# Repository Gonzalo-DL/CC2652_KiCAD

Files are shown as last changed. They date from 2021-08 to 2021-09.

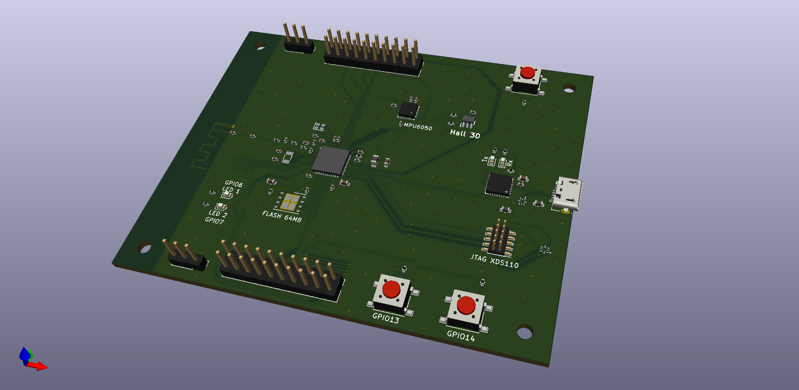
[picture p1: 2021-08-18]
CC2652_OnBoard.png

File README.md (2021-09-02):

# CC2652_KiCAD

PCB con TI CC2652R1 con BLE 5.2 y JTAG con XDS110.

Comunicacion serial via USB conectado a UART y con perifericos:

Led verde: GPIO7

Led rojo: GPIO6

Push button 1: GPIO13

Push button 2: GPIO14

Memoria Flash(W25Q64JWZPIM): (SPI) 

	SCLK: GPIO10
  
	MISO: GPIO8
  
	MOSI: GPIO9
  
	SS: GPIO20

IMU (MPU-6050): (I2C)

	SDA: GPIO24
  
	SCL: GPIO25
  
	FSYNC: GPIO26
  
	Address: 1101000

HALL 3-Axis (TLE493D): (I2C)

	SDA: GPIO24
  
	SCL: GPIO25
  
	Address: (Segun sigla del modelo)
  
		A0: 6AH / 6BH
    
		A1: 44H / 45H
    
		A2: F0H / F1H
    
		A3: 88H / 89H

USB Transceiver (CP2102N): (UART)

	Rx: GPIO19
  
	Tx: GPIO18

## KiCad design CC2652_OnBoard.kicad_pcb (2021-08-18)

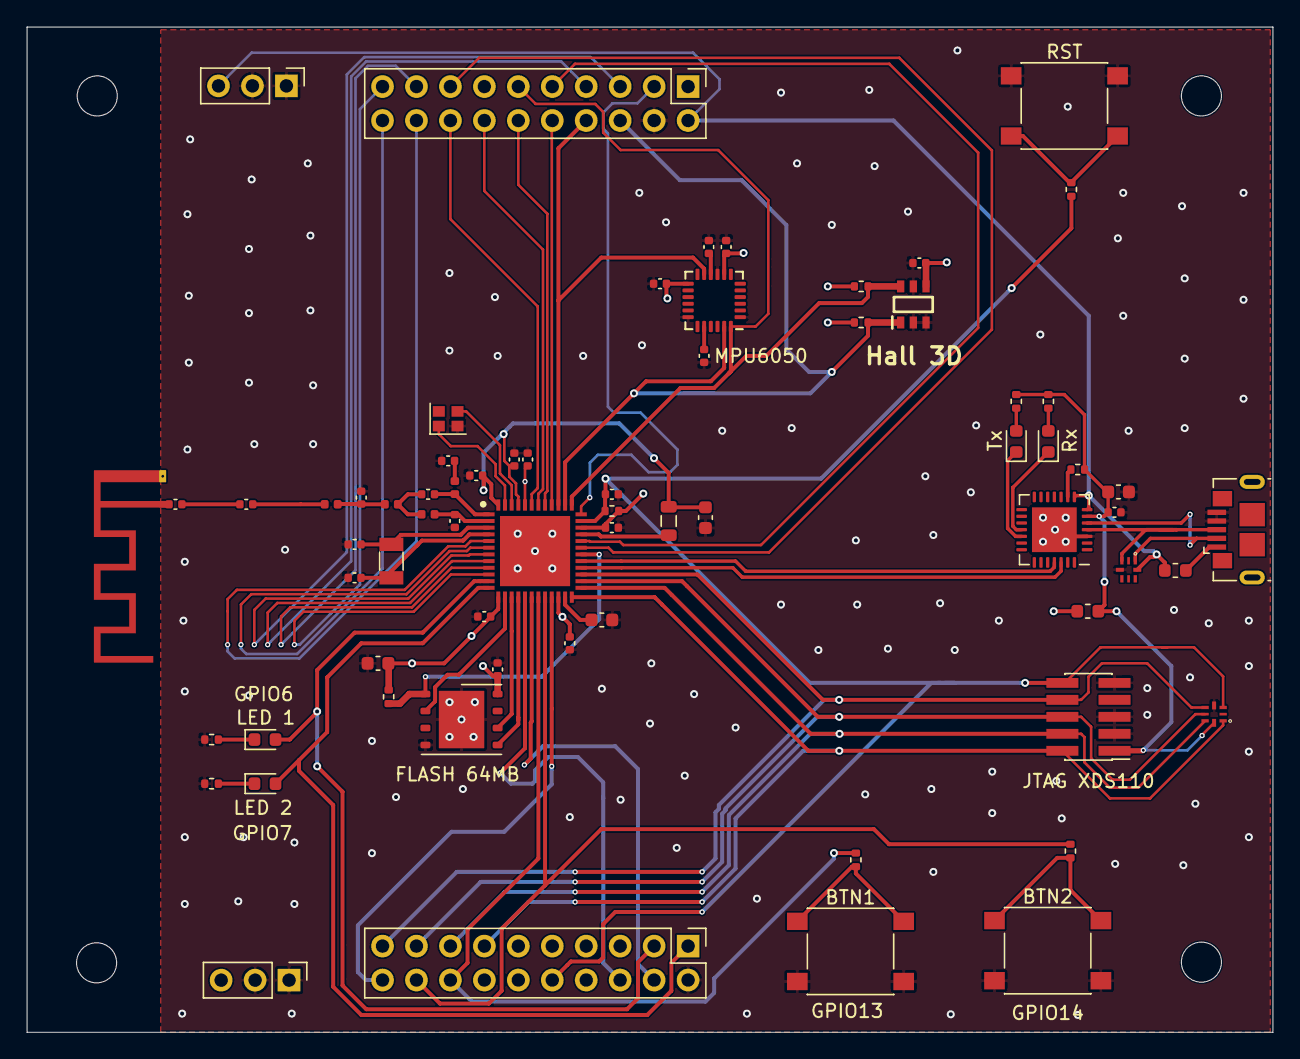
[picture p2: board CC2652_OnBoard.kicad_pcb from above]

Board: 4 copper layers, 93.2 x 75.2 mm, 67 parts (0 on the bottom side), 67 nets.

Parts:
32KHz_Crystl1: 3215 2 pin; Crystal_SMD_3215-2Pin_3.2x1.5mm
48MHz_Crystal1: CX2016DB48000C0FPLC1; Crystal_SMD_2016-4Pin_2.0x1.6mm
BTN1, BTN2: SW; SW_SPST_PTS645
BTN1_R1, BTN2_R1: 100?; R_0402_1005Metric
C1, C2, C303, C305: 12p; C_0402_1005Metric
C3, C102, C103, C104, C105, C106, C107, C108, C109, C111, C112, C204: 0.1u; C_0402_1005Metric
C101: 1u; C_0603_1608Metric
C110: 10n; C_0402_1005Metric
C201, C202: 22u; C_0603_1608Metric
C203: 10u; C_0603_1608Metric
C205: 2.2n; C_0402_1005Metric
C301, C302, C304: 1p; C_0402_1005Metric
C306: 1.8p; C_0402_1005Metric
CP2102_nRST_R1: 10k; R_0402_1005Metric
EMI_VDDS_FILTER1: BLM18HE152SN1D; L_0603_1608Metric
EMI_VDDS_FILTER_USB1: BLM18HE152SN1D; L_0603_1608Metric
FLASH 64MB: W25Q64JWZPIM; WSON-8-1EP_6x5mm_P1.27mm_EP3.4x4.3mm
FLASH_nCS_PUR1: 2.2k; R_0402_1005Metric
HALL_SCL_PUR1: 1k; R_0402_1005Metric
HALL_SDA_PUR1: 1k; R_0402_1005Metric
Hall 3D: TLE493DW2B6A2HTSA1; SOT95P280X110-6N
IC1: CC2652R1FRGZR; QFN50P700X700X100-49N-D
JTAG XDS110: FTSH-105-01; PinHeader_2x05_P1.27mm_Vertical_SMD
JTAG_ESD1: TPD6E004RSER; RSE0008A
L31, L32: 2.4n; L_0402_1005Metric
L33, L34: 2n; L_0402_1005Metric
L101: 6.8u; L_0805_2012Metric
LED 1, LED 2: LED; LED_0603_1608Metric
MPU6050: MPU-6050(I2C); InvenSense_QFN-24_4x4mm_P0.5mm
PINS_DER1: Conn_02x10_Odd_Even; PinHeader_2x10_P2.54mm_Vertical
PINS_IZQ1: Conn_02x10_Odd_Even; PinHeader_2x10_P2.54mm_Vertical
PINS_PWR_DER1: Conn_01x03; PinHeader_1x03_P2.54mm_Vertical
PINS_PWR_IZQ1: Conn_01x03; PinHeader_1x03_P2.54mm_Vertical
R3: 100k; R_0402_1005Metric
RST: SW; SW_SPST_PTS645
R_LED_ROJO1: 180; R_0402_1005Metric
R_LED_USB_Rx1: 180; R_0402_1005Metric
R_LED_USB_Tx1: 220; R_0402_1005Metric
R_LED_VERDE1: 220; R_0402_1005Metric
R_RESET1: 100; R_0402_1005Metric
Rx: rojo; LED_0603_1608Metric
Tx: VERDE; LED_0603_1608Metric
USB_CONNECTOR_A1: U217-041N-4BV81; USB_Micro-B_GCT_USB3076-30-A
USB_ESD1: TPD6E004RSER; RSE0008A
USB_UART1: CP2102N-A01-GQFN28; QFN-28-1EP_5x5mm_P0.5mm_EP3.35x3.35mm

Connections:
CP2102_RX: IC1.29, USB_UART1.25
CP2102_RX_LED: Rx.1, USB_UART1.18
CP2102_TX: IC1.28, USB_UART1.26
CP2102_TX_LED: Tx.1, USB_UART1.19
CP2102_nRST: CP2102_nRST_R1.2, USB_UART1.9
DCDC_OUT: IC1.33, L101.1
FLASH_CLK: FLASH 64MB.6, IC1.15
FLASH_SDI: FLASH 64MB.5, IC1.16
FLASH_SDO: FLASH 64MB.2, IC1.14
FLASH_nCS: FLASH 64MB.1, FLASH_nCS_PUR1.2, IC1.30
GND: 48MHz_Crystal1.2, BTN1.2, BTN2.2, C1.1, C2.1, C3.2, C101.2, C102.1, C103.1, C104.1, C105.1, C106.1, C107.1, C108.2, C109.1, C110.2, C111.1, C112.1, C201.1, C202.1, C203.2, C204.2, C205.1, C301.2, C303.1, C304.2, FLASH 64MB.4, FLASH 64MB.9, Hall 3D.2, Hall 3D.3, Hall 3D.5, IC1.49, JTAG XDS110.3, JTAG XDS110.5, JTAG XDS110.9, JTAG_ESD1.4, MPU6050.1, MPU6050.9, MPU6050.18, PINS_DER1.2, PINS_IZQ1.4, PINS_PWR_DER1.1, PINS_PWR_DER1.2, PINS_PWR_IZQ1.1, PINS_PWR_IZQ1.2, RST.1, R_LED_ROJO1.2, R_LED_VERDE1.2, USB_CONNECTOR_A1.4, USB_CONNECTOR_A1.5, USB_ESD1.4, USB_UART1.3, USB_UART1.29
GPIO0: IC1.5, PINS_IZQ1.18
GPIO1: IC1.6, PINS_IZQ1.20
GPIO2: IC1.7, PINS_IZQ1.5
GPIO3: IC1.8, PINS_IZQ1.7
GPIO4: IC1.9, PINS_IZQ1.17
GPIO5: IC1.10, PINS_IZQ1.19
GPIO6: IC1.11, LED 1.2, PINS_DER1.3
GPIO7: IC1.12, LED 2.2, PINS_DER1.1
GPIO11: IC1.17, PINS_DER1.6
GPIO12: IC1.18, PINS_DER1.4
GPIO13: BTN1_R1.1, IC1.19, PINS_DER1.16
GPIO14: BTN2_R1.1, IC1.20, PINS_DER1.18
GPIO15: IC1.21, PINS_DER1.20
GPIO16-JTDO: IC1.26, JTAG XDS110.6, JTAG_ESD1.6, PINS_DER1.17
GPIO17-JTDI: IC1.27, JTAG XDS110.8, JTAG_ESD1.5, PINS_DER1.19
GPIO21: IC1.31, PINS_IZQ1.15
GPIO22: IC1.32, PINS_IZQ1.9
GPIO23: IC1.36, PINS_IZQ1.3
GPIO24: HALL_SDA_PUR1.2, Hall 3D.6, IC1.37, MPU6050.24, PINS_IZQ1.11
GPIO25: HALL_SCL_PUR1.2, Hall 3D.1, IC1.38, MPU6050.23, PINS_IZQ1.6
GPIO26: IC1.39, MPU6050.11, PINS_IZQ1.8
GPIO27: IC1.40, PINS_IZQ1.10
GPIO28: IC1.41, PINS_IZQ1.12
GPIO29: IC1.42, PINS_IZQ1.14
GPIO30: IC1.43, PINS_IZQ1.16
JTAG_TCKC: IC1.25, JTAG XDS110.4, JTAG_ESD1.7, PINS_DER1.15
JTAG_TMSC: IC1.24, JTAG XDS110.2, JTAG_ESD1.1, PINS_DER1.13
unnamed: BTN1.1, BTN1_R1.2
unnamed: BTN2.1, BTN2_R1.2
unnamed: RST.2, R_RESET1.2
unnamed: C101.1, IC1.23
unnamed: C204.1, MPU6050.10
unnamed: C205.2, MPU6050.20
unnamed: C302.1, L31.2, L33.1
unnamed: C303.2, L32.1
unnamed: C304.1, L33.2, L34.1
unnamed: C305.1, C306.2
unnamed: C305.2, L34.2
unnamed: R_LED_USB_Rx1.2, Rx.2
unnamed: R_LED_USB_Tx1.2, Tx.2
unnamed: EMI_VDDS_FILTER_USB1.2, USB_CONNECTOR_A1.1
unnamed: LED 1.1, R_LED_ROJO1.1
unnamed: LED 2.1, R_LED_VERDE1.1
RESET_N: C3.1, IC1.35, JTAG XDS110.10, JTAG_ESD1.3, PINS_DER1.10, R3.2, R_RESET1.1
RF_N: C301.1, IC1.2, L31.1
RF_P: C302.2, IC1.1, L32.2
USB_D+: USB_CONNECTOR_A1.3, USB_ESD1.3, USB_UART1.4
USB_D-: USB_CONNECTOR_A1.2, USB_ESD1.1, USB_UART1.5
USB_VBUS: EMI_VDDS_FILTER_USB1.1, PINS_IZQ1.2, PINS_PWR_IZQ1.3, USB_ESD1.8, USB_UART1.7, USB_UART1.8
VDDR: C106.2, C107.2, C202.2, IC1.45, IC1.48, L101.2
VDDS: C102.2, C103.2, C104.2, C105.2, C109.2, C110.1, C111.2, C112.2, C201.2, EMI_VDDS_FILTER1.1, FLASH 64MB.8, FLASH_nCS_PUR1.1, HALL_SCL_PUR1.1, HALL_SDA_PUR1.1, Hall 3D.4, IC1.13, IC1.22, IC1.34, IC1.44, MPU6050.8, MPU6050.13, PINS_IZQ1.1, PINS_PWR_DER1.3, R3.1
Vin_CC2652: C108.1, C203.1, CP2102_nRST_R1.1, EMI_VDDS_FILTER1.2, JTAG XDS110.1, JTAG_ESD1.8, R_LED_USB_Rx1.1, R_LED_USB_Tx1.1, USB_UART1.6
X32K_Q1: 32KHz_Crystl1.1, C1.2, IC1.3
X32K_Q2: 32KHz_Crystl1.2, C2.2, IC1.4
X48M_N: 48MHz_Crystal1.3, IC1.46
X48M_P: 48MHz_Crystal1.1, IC1.47

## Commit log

2021-08-11 Update PINS
    [CC2652_USB.sch]
2021-08-18 Update+UL PCB
    [CC2652_JTAG.sch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]
